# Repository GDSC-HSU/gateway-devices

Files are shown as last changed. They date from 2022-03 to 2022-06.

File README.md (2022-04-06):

# gateway-devices
Git submodules contain supported device, board-schematic, mock emulator codebase

##### ```SOLUTION IN ACTION```
We submit our solution in GDSC Solution challenge 2022 base on 17 Sustainable Development Goals of the United Nations more info could be found [here](https://developers.google.com/community/gdsc-solution-challenge) 

Youtube : https://www.youtube.com/watch?v=W5LBuIvWCd8

<a href="http://www.youtube.com/watch?feature=player_embedded&v=W5LBuIvWCd8" target="_blank">Gateway - GDSC Solution Challenge 2022</a>
#### Installation
1. Platform IO as our IDE of chose for IoT development
[Platform IO - VScode Install](https://platformio.org/install/ide?install=vscode)
1. Follow this guidance (GUI click-click) to add ESP32 build-tool for PlatformIO [here](https://www.youtube.com/watch?v=5edPOlQQKmo)
1. Wait a bit for ESP32 build-tool to be install in PlatformIO (1.2 GB)
1. [ESP32-BLE/ - Folder](./ESP32-BLE/) contain Platform IO project
1. Change PlatformIO USB PORT base on linux/macos , window [file-path](https://github.com/GDSC-HSU/gateway-devices/blob/1f371f100a37d73364ffd409288a2f706fa2dcd2/ESP32-BLE/platformio.ini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)
1. Platform IO Build with ESP32 board of your choice **`if you don't have required sensor to run the project`** [follow here to enable emulator suite](#dont-have-board-sensor-"problem-solved") for mockup BLE data over serial

```bash
# minimal step for techie 👨🏻‍💻
1. install Platform IO
2. cd ESP32-BLE/
3. install esp32 build-tool for Platform IO (follow GUI click-click)
4. change usb-port (linux/macos [/dev/ttyUSB], window [COM])
5. Build
```

#### Hardware Part
```Part could be order (cheaply) - here are direct link for visual aspect```

##### ```BLE Board```
1. [ESP32 TTGO T8 V1.7](https://vi.aliexpress.com/item/33043952133.html)
##### ``` Sensor part```
1. [Radar motion Sensor : RCWL-0516](https://www.amazon.com/RCWL-0516-Microwave-Induction-Envistia-Mall/dp/B07QMZF1BV)
1. [RFID/NFC : PN532](https://electropeak.com/pn532-nfc-rfid-reader-writer).
1. [Contact-less Infrared Sensor : MLX90614](https://www.adafruit.com/product/1748)
1. [Cheap proximity sensor : UNKNOWN](https://www.engineersgarage.com/proximity-sensors-optical-ultrasonic-inductive-magnetic-capacitive/) support MLX90614 reading in close range

##### ```3D printed model```

```

- 3D-MODEL/
        - box-pn532.stl"
        - esp32-ttgo-box.STL"
        - motion-dection-box.STL"
        - thermal-and-proximity-box.STL"
 ```

#### Wired diagram
``` work in process```

#### 2. IoT division

Flutter application as an testing suite for IoT BLE is hard-complex to develop "within our develop resource and time"

I suggest using [LightBlue® — Bluetooth Low Energy] [IOS](https://apps.apple.com/us/app/lightblue/id557428110) | [Android](https://play.google.com/store/apps/details?id=com.punchthrough.lightblueexplorer&hl=vi&gl=US) [Window,Mac] also avablie if your machine has BLE

We're using a custom BLE GATT profile which means the UUID will be hard to look at but you guys can base on our documentation [here](https://github.com/GDSC-HSU/gateway-devices/blob/master/ble_uuid_conf.yml) where we define our BLE GATT services, characteristics.

```yml
gatt_profile:
  - BLE_SERVICE_THERMOMETER_UUID: "00000B00-5226-4AE0-8977-656FD3C42DA2"
```

When you get familiar with LightBlue, you will be able to know that every time the BLE board notify LightBlue will get it. But the format is kind of a mess so you have to **decode **it I suggest using a tool on the website http://www.unit-conversion.info/texttools/ascii/ to decode and see the value has been transfer over BLE protocol

```yml
BLE GATT:
 BLE_SERVICE_THERMOMETER_UUID: "00000B00-5226-4AE0-8977-656FD3C42DA2"
data:
 051 051 (ascii) => String: => 33 (ascii decode to text)
meaning: Data from THERMOMETER is 33 
```
---

##### Don't have board sensor "problem solved"
> What I would do when i don't have sensor to connect to BLE Board

You will use **BLE_SENSOR_EMULATOR** in short it allows your machine (PC) talk to BLE Board (ESP32) over serial and send data over BLE GATT.
**BLE_SENSOR_EMULATOR** are [located here](https://github.com/GDSC-HSU/gateway-devices/blob/master/serial_taklker.py) is a Python script with serial comunication

**```step to use```** 

1. Config your **```machine PORT```** in the Python script [here](https://github.com/GDSC-HSU/gateway-devices/blob/f8e9ac8967a8b4b7791e6821dc9990c71e83f9cd/serial_taklker.py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)
1. **`Config DEBUG MODE`** in C++ project [located here](./ESP32-BLE/src/device_config.h)
###### Example of BLE SERIAL EMULATOR config

```c
#ifndef DEVICE_CONFIG_H
#define DEVICE_CONFIG_H
/// BLE SERIAL EMULATOR
/// uncomment as enable BLE SERIAL EMULATOR MODE
#define DEBUG

/// SENSOR DATA LOG
#define DEBUG_DATA_LOG
#endif
```
1. base on while loop it will call BLE Board to send each package, you could re-configure to your liking

=> if you still on LightBLue you will see the data been notify

```mermaid
sequenceDiagram
    participant IoT
    participant Mobile
    rect rgb(100, 159, 100)
    IoT->>Mobile:devlopemnt_enviorment
    alt is_ble
        Note over IoT,Mobile:real hardware mobile
    else
        Note over IoT,Mobile:mobile emulator for UI
    end
    end
```

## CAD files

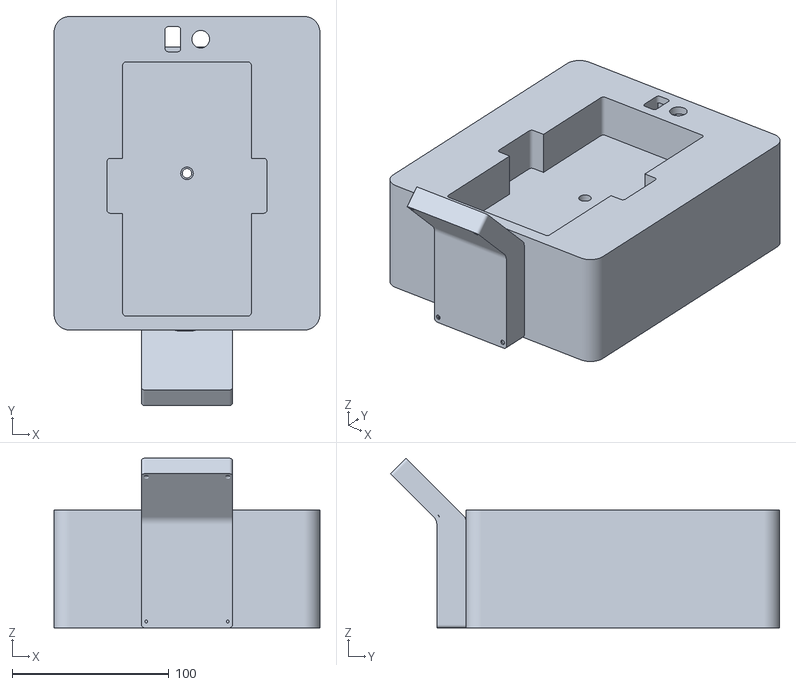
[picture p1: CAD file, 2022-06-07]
3D-MODEL/gateway-box-enclosure.stl
169.5 x 248.1 x 108.2

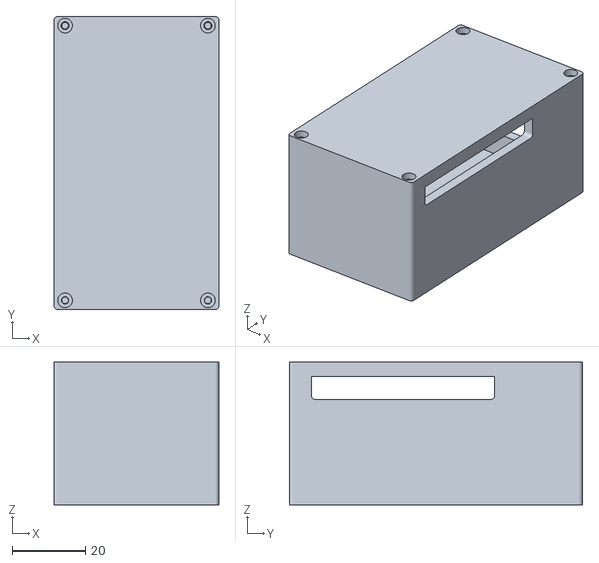
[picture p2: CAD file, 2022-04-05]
3D-MODEL/esp32-ttgo-box.STL
45.0 x 80.0 x 39.0

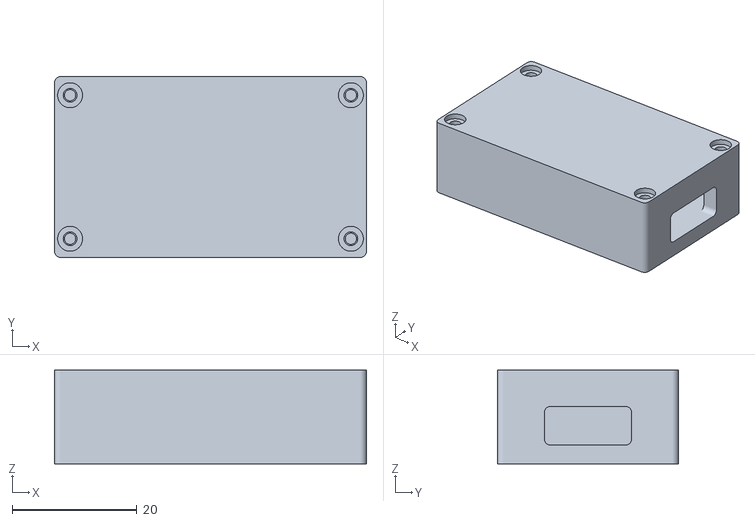
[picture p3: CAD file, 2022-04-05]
3D-MODEL/motion-dection-box.STL
50.0 x 29.0 x 15.0

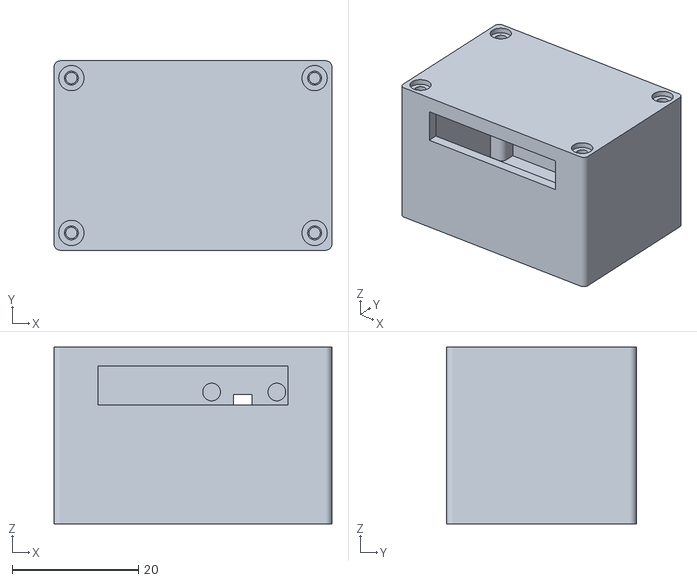
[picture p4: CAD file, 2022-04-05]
3D-MODEL/thermal-and-proximity-box-v2.STL
44.0 x 30.0 x 28.0

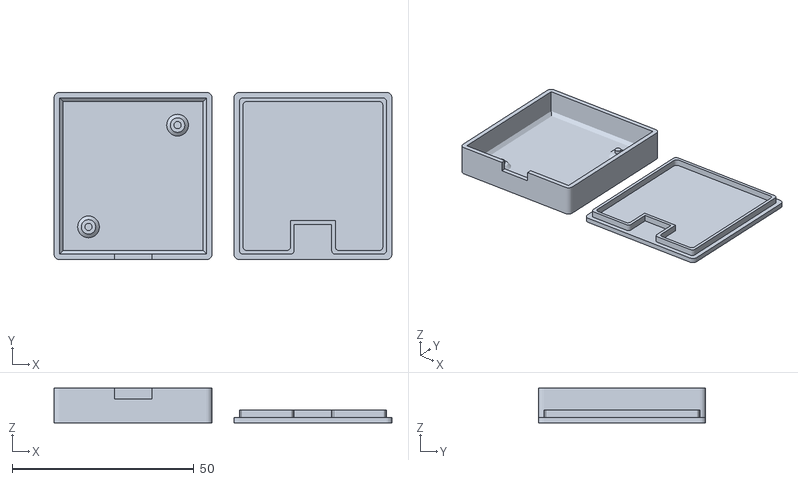
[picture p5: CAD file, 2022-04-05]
3D-MODEL/box-pn532.stl
93.0 x 46.0 x 9.50

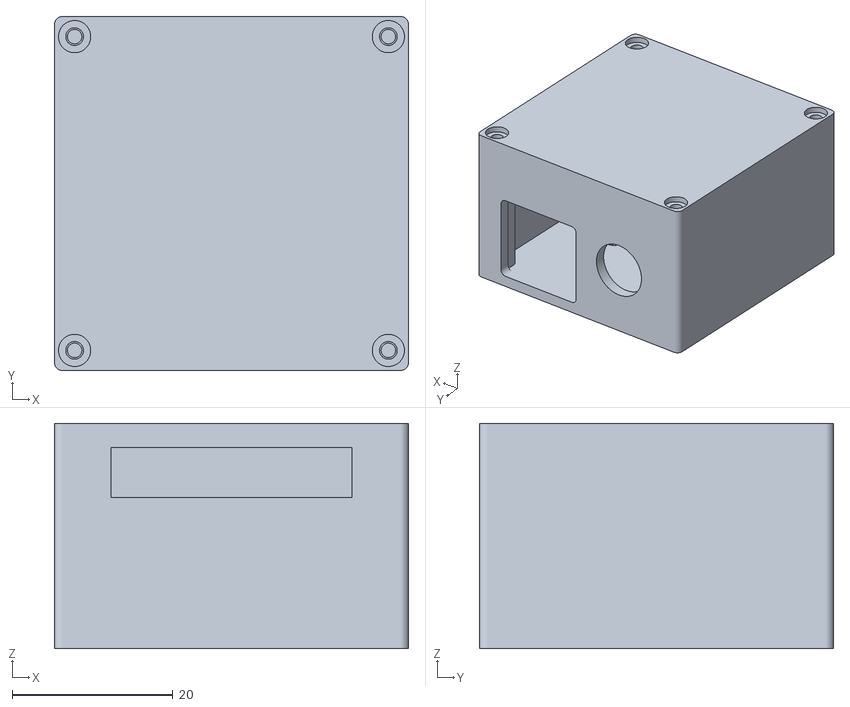
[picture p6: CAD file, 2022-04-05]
3D-MODEL/thermal-and-proximity-box.STL
44.0 x 44.0 x 28.0

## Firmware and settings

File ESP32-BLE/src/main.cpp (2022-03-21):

#include <Arduino.h>
#include <device_config.h>
#include <NimBLEDevice.h>
#include <BLE_DESIGN.g.h>

///
#ifndef Adafruit_MLX90614_H
#define Adafruit_MLX90614_H
#include <Adafruit_MLX90614.h>
#endif
//

#include <PN532_SPI.h>
#include <PN532.h>
#include <NfcAdapter.h>
//
#include <MyBLE.h>

//
#include <MySensor.h>

///
#include <Bounce2.h>


// gpServer is use to controlling BLE GATT with sensor
static NimBLEServer *gpServer;

// Hidden wrapper for gatt server setup & control central pairing
static MyBLE myBLE;
static MySensor mySensor;

Adafruit_MLX90614 mlx = Adafruit_MLX90614();
PN532_SPI interface(SPI, 5);
NfcAdapter nfc = NfcAdapter(interface);
Bounce radarBounce = Bounce(); // Instantiate a Bounce object

void setup()
{
  Serial.begin(115200);
  Serial.println("Starting BLE server");
  NimBLEDevice::init(DEVICE_NAME);
  NimBLEDevice::setPower(ESP_PWR_LVL_P9);
  gpServer = NimBLEDevice::createServer();
  myBLE.init(gpServer);
  delay(1000);
  #ifndef DEBUG
  mySensor.init(&myBLE, &nfc, &mlx);
  delay(1000);
  radarBounce.attach(RADAR_PIN, INPUT);
  #endif
}

#ifdef DEBUG
/* TODO mock create fake sensor data :> (currently in order & shipping :>)
  - [x] proximity
  - [x] thermometer
*/
// TODO web-client for to controlling sensor over serial (python,nodejs maybe)
// using keyboard input suck, web forward port client UI just click click :)) we could writing ours testcases
// key/data (97:15)-> 97 for calling proximity - 15cm in range :>

// control sensor data state and calling gatt services and characteristics
String serialInput;
int key;
String value;

void parsingCommandFromSerial()
{
  serialInput = Serial.readStringUntil('\n');
  int index = serialInput.indexOf(":");
  key = atoi(serialInput.substring(0, index).c_str());
  value = serialInput.substring(index + 1, serialInput.length());
}
#endif


void loop()
{
#ifdef DEBUG

  // BLE SENSOR DATA SERIAL COMMUNICATION EMULATOR
  while (Serial.available())
  {
    parsingCommandFromSerial();
    Serial.println(key);
    switch (key)
    {
    case 1:
      myBLE.setProximity(value);
      break;
    case 2:
      myBLE.setThermometer(value);
      break;
    case 3:
      myBLE.setRadar(value);
      break;
    case 4:
      myBLE.setRFID(value);
      break;
    default:
      break;
    }
    Serial.println(value);
    Serial.flush();
  }
#endif

#ifndef DEBUG
/* TODO common interface for logging in 
 - [] MySensor 
 - [] MyBLe
*/
if (myBLE.isMobileConnected())
{
 
  radarBounce.update();
 if (radarBounce.rose())
 {
    mySensor.isMotionApper();
 }
 if(radarBounce.fell()){
    mySensor.isMotionApper();
 }
 if(radarBounce.read()== HIGH){
    mySensor.readRFID();
    if (mySensor.isThermometerProximityEnough())
    {
      mySensor.readThermometer();
    }
 }
}

// Serial.println(radarBounce.read());
#endif
}

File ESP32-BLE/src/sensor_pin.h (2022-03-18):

#define RADAR_PIN 14
#define SDA_PIN 21
#define SDL_PIN 22
#define SPI_CS 5
#define THERMOMETER_PROXIMITY_PIN 26

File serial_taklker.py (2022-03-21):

#! /usr/local/bin/python3
import os
import serial
import time
import random
import sys
import uuid
# its win32, maybe there is win64 too?
is_windows = sys.platform.startswith('win')

PORT = "/dev/tty.usbserial-A50285BI"

if is_windows:
    PORT = "COM5"

arduino = serial.Serial(port=PORT,
                        baudrate=115200, timeout=.1)
counter = 0
key = 0
text = ""


def clear(): return os.system('cls' if os.name == 'nt' else 'clear')


def getUUID():
    totalByte = 22
    return uuid.uuid4().hex[0:totalByte]


def proximity_emulator():
    global text
    key = 1
    num = random.randrange(10, 20)
    formatedText = '''{key}:{counter}'''.format(key=key, counter=num)
    text = formatedText


def thermometer_emulator():
    global text
    key = 2
    num = random.randrange(33, 40)
    formatedText = '''{key}:{counter}'''.format(key=key, counter=float(num)+0.1)
    text = formatedText


def rfid_emulator():
    global text
    key = 4
    num = getUUID()
    formatedText = '''{key}:{counter}'''.format(key=key, counter=num)
    text = formatedText


def radar_emulator():
    global text
    key = 3
    num = random.randrange(0, 1)
    formatedText = '''{key}:{counter}'''.format(key=key, counter=num)
    text = formatedText


def runner(callbackList):
    # callback List as *_emulator() function
    for callback in callbackList:
        callback()
        arduino.write(bytes(text, 'utf-8'))
        time.sleep(0.5)


def suite_normal():
    runner([
        proximity_emulator, thermometer_emulator, rfid_emulator,
    ])


def text_to_sensor(text):
    if text == "2":
        return thermometer_emulator
    if text == "3":
        return radar_emulator
    if text == "1":
        return proximity_emulator
    if text == "4":
        return rfid_emulator
    return ""


sensor_table = [["1:", "proximity_emulator"], ["2:", "thermometer_emulator"], [
    "3:", "radar_emulator"], ["4:", "rfid_emulator"]]


while 1:
    print("Type in sensor number to emulate over ble")
    print("-----------")
    for i in sensor_table:
        print('\t'.join(i))
    print("-----------")
    sensorType = input("type in number : ")
    if sensorType != "":
        runner([text_to_sensor(sensorType)])
    else:
        print("Wrong format")
        time.sleep(1.5)
    clear()
    # if text == "":
    #     runner(
    #         [proximity_emulator, thermometer_emulator]
    #     )

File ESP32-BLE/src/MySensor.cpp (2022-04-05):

#include "MySensor.h"

MySensor::MySensor() {}

void MySensor::isSensorBeginFail(bool beginResult, String sensorName)
{
    if (!beginResult)
    {
        Serial.println("[Dev Error] sensor fail " + sensorName);
    }
}

void MySensor::log(String sensorName , String data)
{
    #ifdef DEBUG_DATA_LOG
        Serial.println("[DEV] SensorData:" + sensorName + "\t" + data);
    #endif
}

void MySensor::init(MyBLE *myBLE, NfcAdapter *nfc, Adafruit_MLX90614 *mlx)
{
    ptr_MyBLE = myBLE;
    initThermometer(mlx);
    initNFC(nfc);
    initRadarProximity();
    initThermometerProximity();
}
void MySensor::initThermometer(Adafruit_MLX90614 *mlx)
{
    bool isWireBegin = Wire.begin(SDA_PIN, SDL_PIN);
    isSensorBeginFail(isWireBegin, "Wire: Adafruit_MLX90614");
    ptr_MLX = mlx;
    bool isMlxBegin = ptr_MLX->begin();
    isSensorBeginFail(isMlxBegin, "Adafruit_MLX90614");
}

void MySensor::initRadarProximity()
{
    // OneButton hanlder
    // pinMode(RADAR_PIN, INPUT);
}

void MySensor::initNFC(NfcAdapter *nfc)
{
    ptr_NFC = nfc;
    ptr_NFC->begin();
}

void MySensor::initThermometerProximity(){
    pinMode(THERMOMETER_PROXIMITY_PIN,INPUT);
}

///----------------------------------
// SENSOR READING

void MySensor::readRFID(bool isNotify)
{
    // void readNFC()
    // {
    if (ptr_NFC->tagPresent())
    {
        NfcTag tag = ptr_NFC->read();
        String tagID = tag.getUidString();
        log("NFC",tagID);
        if (isNotify)
        {
            ptr_MyBLE->setRFID(tagID);        
        }
    }
    // }
}

bool MySensor::isMotionApper(bool isNotify)
{
    // TODO add millis
    int isMotionApper = digitalRead(RADAR_PIN);
    String isMotionApperAsString = String(isMotionApper);
    log("Motion",isMotionApperAsString);
    if (isNotify)
    {
        ptr_MyBLE->setRadar(isMotionApperAsString);
    }
    
    return isMotionApper;
}

void MySensor::readThermometer(bool isNotify)
{
    String temp = String(ptr_MLX->readObjectTempC());
    log("Thermometer",temp);
    if (isNotify)
    {
        ptr_MyBLE->setThermometer(temp);
    }
    
}

bool MySensor::isThermometerProximityEnough(){
    short value = digitalRead(THERMOMETER_PROXIMITY_PIN);
    log("ThermometerProximityEnough",String(value));

    return !value;
}

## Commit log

2021-10-09 my fris workable BLE tnotifier ✅
2021-10-14 adding todos 😅
2021-10-15 thermometer sensor emulator
2021-10-15 expose device name on bote platfrom
2021-10-15 fix ESP32 device name with ble generator
    [ble_uuid_generator.py, main.cpp]
2022-02-06 fix: debug serial prasing
    [main.cpp]
2022-03-01 add lib sensor Adafruit_MLX90614.h
2022-03-04 fix: arduino port
2022-03-12 add lib SPI MLX
2022-03-14 feat: :rocket: implement ours libary sensor
2022-03-15 add sensor libary
2022-03-15 feat: :zap: when mobile connected, enable sensor reading with radar state
    required testing for debounce
2022-03-18 test: :art: add debug header for sensor data
2022-03-21 fix: :bug: `DEBUG MODE` disable section of `MySensor`
    [main.cpp, serial_taklker.py]
2022-04-05 ref: remove raspberrypi with bleno
2022-04-05 fix: change to new proximity sensor
    [MySensor.cpp]
2022-04-05 docs: :rocket: add `3D MODEL` STL formated
    SLDPRT exported
    [box-pn532.stl, esp32-ttgo-box.STL, motion-dection-box.STL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]
2022-04-06 add: `3d printed` in docs
2022-06-07 add: `3D printed` enclosure for high deployment
    [gateway-box-enclosure.stl]
